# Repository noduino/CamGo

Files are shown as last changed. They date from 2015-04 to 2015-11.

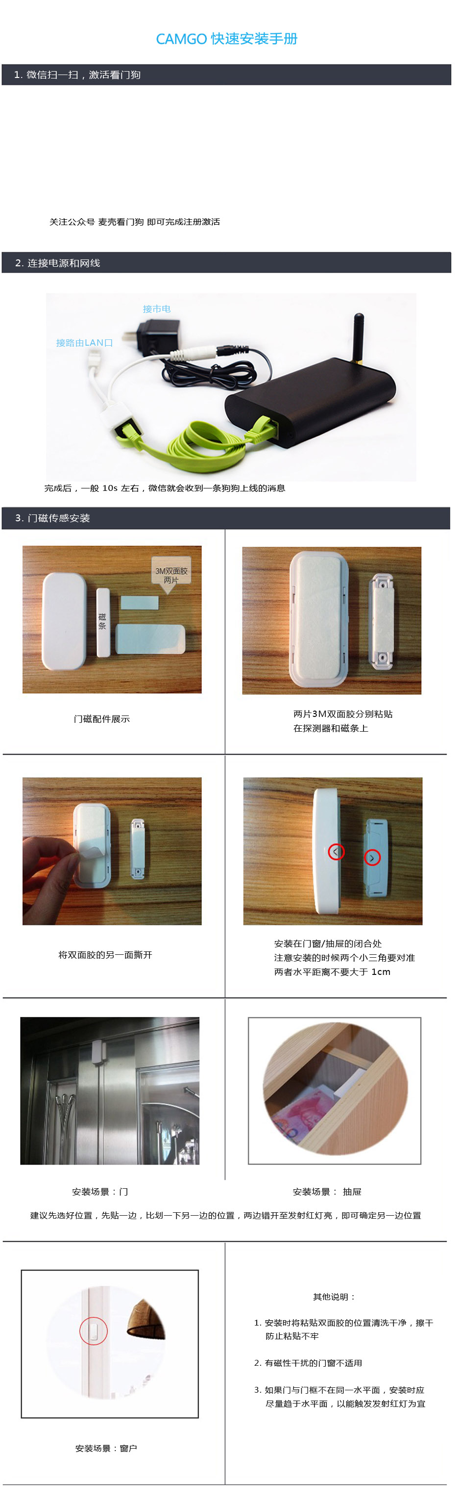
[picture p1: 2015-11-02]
user-manual.jpg

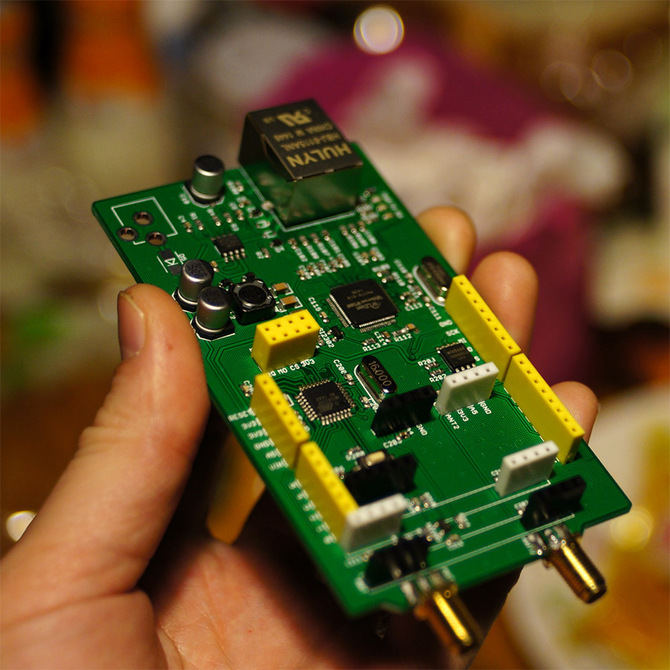
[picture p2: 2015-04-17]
Geek.Board.jpg

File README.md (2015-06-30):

# CamGo
Smart Home Dog to monitor 315&433MHz Sensors, Switches ...

Sensors:

  * door open sensor
  * wireless door bell
  * smoke detection (wireless alarm)
  * gas detection (wireless alarm)
  * wind & rain sensor
  ......

Switchs:

  * 315/433 light switch
  * dooya curtion
  * automatic window
  ......

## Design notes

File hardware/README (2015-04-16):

Copyright 2015 MaiKe Labs

These files are part of CamGo.

This is a free hardware design; you can redistribute it and/or modify
it under the terms of the GNU General Public License as published by
the Free Software Foundation; either version 2, or (at your option)
any later version.

This design is distributed in the hope that it will be useful,
but WITHOUT ANY WARRANTY; without even the implied warranty of
MERCHANTABILITY or FITNESS FOR A PARTICULAR PURPOSE.  See the
GNU General Public License for more details.

You should have received a copy of the GNU General Public License
along with this design; see the file COPYING.  If not, write to
the Free Software Foundation, Inc., 51 Franklin Street,
Boston, MA 02110-1301, USA.

CamGo is a Smart Home Gateway for 315MHz, 433MHz Sensors and Switches 

hardware notes:

Schematic and layout files were designed in Eagle.

PCB description: 2 layer PCB 0.062 in
    Copper        1   0.5 oz foil plated to approximately 0.0017 in
    Copper        2   0.5 oz foil plated to approximately 0.0017 in

FR4 or similar substrate with Er=4.5 (+/- 0.1)
double side solder mask green
single side silkscreen white
6 mil min trace width and
6 mil min isolation

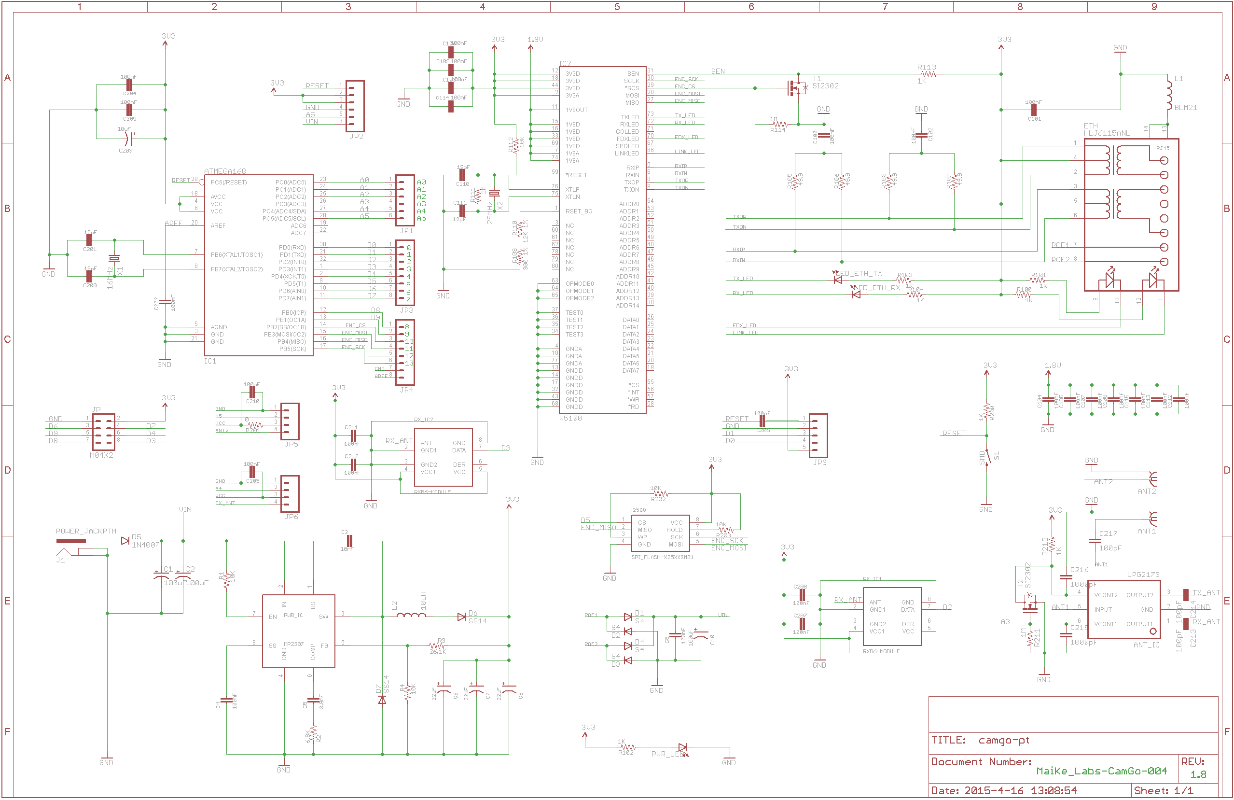
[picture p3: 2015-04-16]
hardware/CAMGO-SCH.png

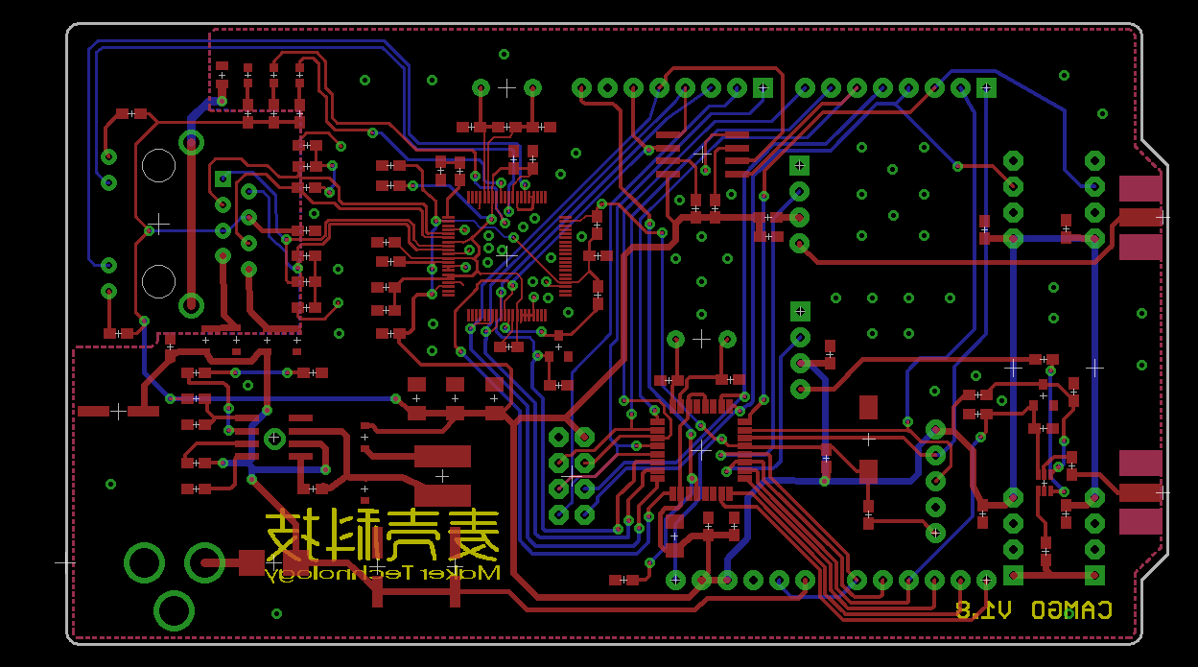
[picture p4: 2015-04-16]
hardware/CAMGO-BRD.png

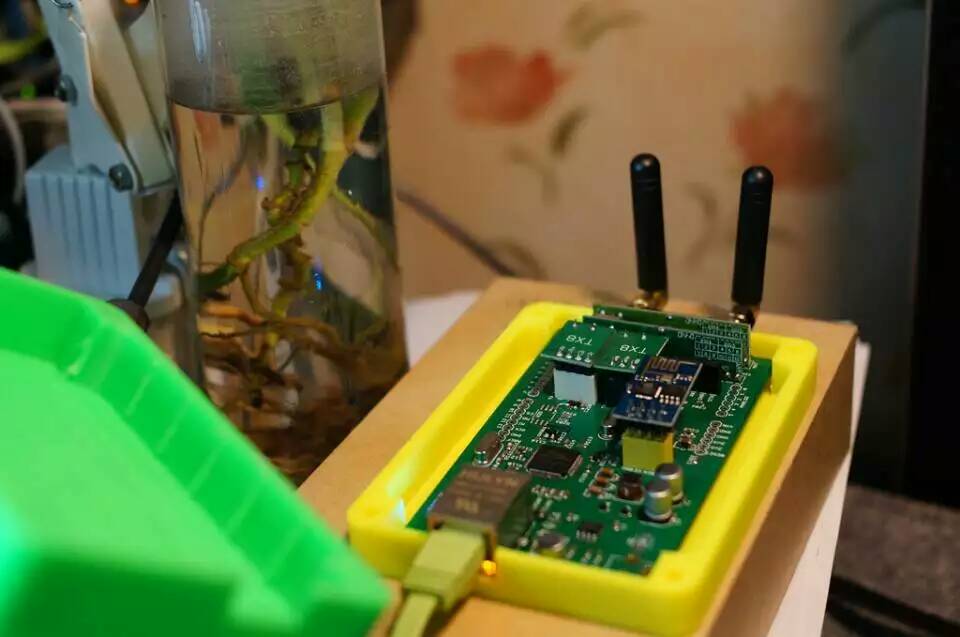
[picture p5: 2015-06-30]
shell/dogy/dogy-02.jpg

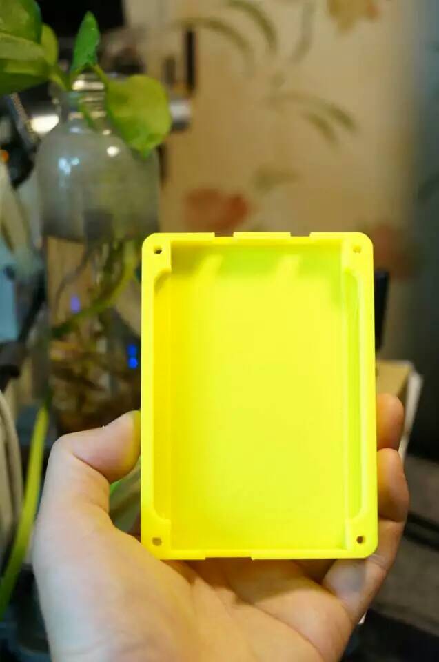
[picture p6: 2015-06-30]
shell/dogy/dogy-01.jpg

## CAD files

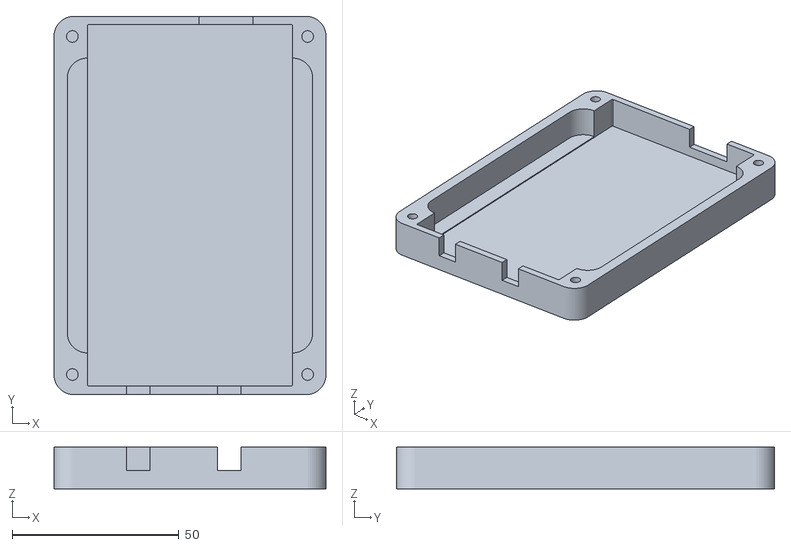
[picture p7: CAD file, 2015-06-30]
shell/dogy/dogy-bottom-v1.stl
81.5 x 113.2 x 12.5

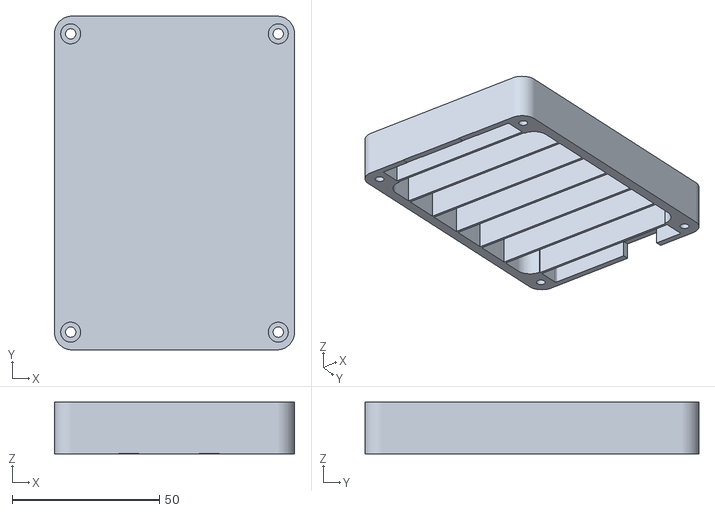
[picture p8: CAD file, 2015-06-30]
shell/dogy/dogy-lid-v1.stl
81.5 x 113.2 x 17.6

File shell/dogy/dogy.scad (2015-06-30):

include <../lib/plus.scad>

thick=1.6+0.25+0.5;
w=61.22+0.25; //compasate 0.3
len=108+0.25;

$fn=60;

boxh=26; //internal
boxbh=12.5;
tb_thick=2; // top,bottom wall thick

module ethernet(quad=3) {
    // we go 'underground' as we need to poke space into the case
    color("silver") 
      Quad(21.12, 15.92, quad) 
       Cube(size=[21.12+6, 15.92+0.25, 13.3]);
}

module sma(){
    
   Cube(7,45,7);
}

module board(h){ //h: cut the box
  
  onboard=thick+1.15; //include the bottom pin
  //base pcb
  color("darkgreen")
     CubeR(w, len, h, r=0.5); //+15 for dig hole
  
  //eth port
  translate([w/2-12-15.92,len/2,onboard])//bottom pin 1.5
     rotate(90)
      ethernet();
    
  //ant
  for(p=[(w/2-7-12),-15.5])
     translate([p,-len/2,onboard])//z, on the board
       sma();
    
}


module holes(){

    translate([0, pad,2]) //board, 2: bootom thick
       //
       difference(){
         board(boxh);
      
       }
       
    // translate([0,7+pad-5,boxbh-2*pad]) //board
      //   Cube(w, len+5, boxh-boxbh-thick);
     
     translate([0,0])
       scatter_conner([w+9,len-7])
          up(-pad)hextraper();//screw mount
     /*
     translate([0,-len/2+3])
        translate([0,-150/2])
           up(-pad)Cube(150,150,50);//screw mount
     */
     translate([w/2,0])
         up(thick)CubeR(12,len-20,25, r=6);//screw mount
     translate([-w/2,0])
         up(thick)CubeR(12,len-20,25, r=6);//screw mount
       
    
}
module box(){
  wallthick=10;  
 
  difference(){
        //base
        union(){
        
            CubeR(w+wallthick*2, len+wallthick/2, boxh+tb_thick*2, r=6);

       }
    
    //holes
      difference(){
       holes();
       for (p=[0,15,30,45,-15,-30,-45])
           translate([0,p])
            Cube(w+50,1,boxh);
      }
   }

}

//testant();



module lid(){
    
  intersection(){
      box();
      up(boxbh-0.1)
        Cube(500,500,25);
  }
   
}

module blid(){
    
  difference(){
      box();
      up(boxbh)
        Cube(200,200,25);
  }
    
     
    
}

//box();
//blid();
//rotate([0,180])up(-boxh-tb_thick*2)
lid();



module testeth(){
intersection(){
  box();

 translate([0,len/2,0])
   Cube(w+5,20,33);

}

}



module testant(){
intersection(){
  box();
 translate([0,-len/2,0])
   Cube(w+5,18,44);

}

}


module hextraper(len=15){
    
    
          translate([0,0, 0])
         	    cylinder($fn=6, r2=(6.26+0.2)/2,r1=(6.26+0.7)/2, h=5);
          translate([0,0, 5+0.5])
		     	cylinder($fn=33, r=3.5/2, h=50);
           
          // sink screw
          //translate([0,0, -11.3])cylinder($fn=33, r2=3.4/2,r1=6.8/2, h=3);
          // screw slot
          translate([0,0,15])cylinder($fn=33, d=6.8,h=35);

}

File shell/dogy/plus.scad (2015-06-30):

pad=0.05; /*make sure no malform or wrong object*/


green=[0.1,0.9,0.2,0.8];
black=[0.3,0.3,0.3,1];

fgreen=[0.3, 0.9, 0.2, 0.95];
fgold=[1,0.85, 0.1, 0.95];
fblue=[0.2,0.2,0.79];

//position helper
function cot(x)=1/tan(x);

module up(z){
    translate([0,0,z])
      children();
}

//basic shape 
module Cube(x,y,z,size){
  

   //echo("size", size);
   if(size){
     translate([0,0,size[2]/2])
       cube(size,center=true);
   }else{
     translate([0,0,z/2])
       cube([x,y,z],center=true);
     
   }


}

//test
//Cube(13,13,3);

module chamfer_cylinder(r,d,h,ch,crt,cdt,cdb,crb)
{
 	union(){
		 translate([0,0,h-ch])
	    	 cylinder(r1=r,d1=d, r2=crt,d2=cdt,h=ch);
         translate([0,0,ch])
  	       cylinder(r=r,d=d,h=h-ch*2);
         cylinder(r2=r,d2=d, r1=crb,d1=cdb,h=ch);
	}
}

module M3HexScrew(len=10, r=3){
      chamfer_cylinder(r=r/2,h=len-2*2, ch=2,crt=r/2,crb=7/2);
}


//chamfer_cylinder(r=10, h=10, crt=15,crb=15,ch=3);




/////////////////////////////////////////////////////////
// position helper
module quadI(x, y){
    translate([x/2, y/2]){
       children();    
    }
}
module quadII(x, y){
    translate([-x/2, y/2]){
       children(); 
    }
}
module quadIII(x, y){
    translate([-x/2, -y/2]){
       children();    
    }
    
}
module quadIV(x, y){
    translate([x/2, -y/2]){
       children();    
    }
}
module Quad(x, y, quad=0){

   if(quad==1)
       quadI(x,y)
            children();
   if(quad==2)
       quadII(x,y)
            children(); 
   if(quad==3)
       quadIII(x,y)
            children(); 
   if(quad==4)
       quadIV(x,y)
        children(); 

}
/////////////////////////////////////////////////////////
module scatter_conner(size=[0,0,0]){
    /*given x,y, (z) get 4 corner coordinates
                 Y
                /
          [2,  / 1]
         -----+---->X
         [3, /   4]
    */
    x=size[0]/2.0;
    y=size[1]/2.0;
    z=size[2];
    vet=[[ x,  y, z],
            [-x,  y, z],
            [-x, -y, z],
            [ x, -y, z]
        ];
    for (v=vet)
       translate(v)
          children();
}

/////////////////////////////////////////////////////////

module Sphere(r=none, d=none){
  if(r)
     translate([0,0,r])
     sphere(r=r);
  else
     translate([0,0,d/2]) 
     sphere(d=d);
}

//Sphere(d=3);




module CubeR(x,y,z,r){ CubeRZ(x=x,y=y,z=z,r=r);}
module CubeRZ(x,y,z,r){ CubeRXYZ(x=x,y=y,z=z,rz=r);}
module CubeRY(x,y,z,r){ CubeRXYZ(x,y,z,ry=r);}
module CubeRX(x,y,z,r){ CubeRXYZ(x,y,z,rx=r);}
module CubeRR(x,y,z,r){CubeRXYZ(x=x,y=y,z=z,rx=r,ry=r,rz=r,rc=r);}
module CubeRXYZ(x,y,z,r,rx,ry,rz,rc){
    difference(){
        Cube(x=x,y=y,z=z);
        //z
        if(rz)
        for(q=[1:4])
          Quad(x,y,q) up(-pad) 
           _RoundSmooth(l=z+pad*2,r=rz);
        //y
        if(ry){
            for(q=[1:2])
              Quad(x,y,q) up(-pad)
                rotate([90,0,0])up(-pad)_RoundSmooth(l=y+2*pad,r=ry);
            for(q=[3:4])
               Quad(x,y,q)translate([0,y,z])
                rotate([90,0,0])up(-pad)_RoundSmooth(l=y+2*pad,r=ry);
        }
        //x
        if(rx){
            for(q=[2,3])
                Quad(x,y,q) up(-pad)
                  rotate([0,90,0])up(-pad)_RoundSmooth(l=x+2*pad,r=rx);
            for(q=[1,4])
                Quad(x,y,q) translate([-x,0,z])
                  rotate([0,90,0])up(-pad)_RoundSmooth(l=x+2*pad,r=rx);
       }
       
       if(rc){
        for(q=[1,2,3,4])
          Quad(x,y,q)
            _RoundSmoothConner(rc);
          for(q=[1,2,3,4])
          Quad(x,y,q)
            up(z)
            _RoundSmoothConner(rc);
       }
  }
    
}

module _RoundSmoothConner(r){
    translate([0,0,-r])
    difference() {
        Cube(r*2, r*2, r*2);
        
        for(q=[1:4])
          Quad(2*r,2*r,q)
            sphere(r);
        for(q=[1:4])
          up(2*r)
           Quad(2*r,2*r,q)
             sphere(r+pad);
     }
 }
//$fn=45;
//_RoundSmoothConner(r=5);
 module _RoundSmooth(r, l){
   //translate([-r,-r,0])
   difference(){
    Cube(2*r, 2*r, l);
     for(q=[1:4])
       Quad(2*r-pad,2*r-pad,q) //pad: critical for export water tight
           up(-pad)cylinder(r=r,h=l+2*pad);
   }
}
//CubeR(5,5,5,r=1);

//speed test
//for(i=[1:50]) translate([i*10,0,0]) %_CubeFR_(10,5*i,5, r=2);
//for(i=[1:50])translate([i*10,0,0]) %CubeR(10,5*i,5,r=2);

module Hex(width,thick){
  
  angle = 360/6;		// 6 pans
  side = width*cot(angle);
  for (i=[0,60, 120])
    rotate(i)  
       Cube(side,width,thick);
    
}


///////////////////////////////////////////////
//dropped 
module CubeR__slow(x,y,z,r){
  size=[x-2*r, y-2*r, 0];  
  
  hull(){
    scatter_conner(size)
       cylinder(r=r, h=z);  
  }   
    
}

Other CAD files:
shell/official/rear-panel.dwg
shell/official/frant-panel.dwg

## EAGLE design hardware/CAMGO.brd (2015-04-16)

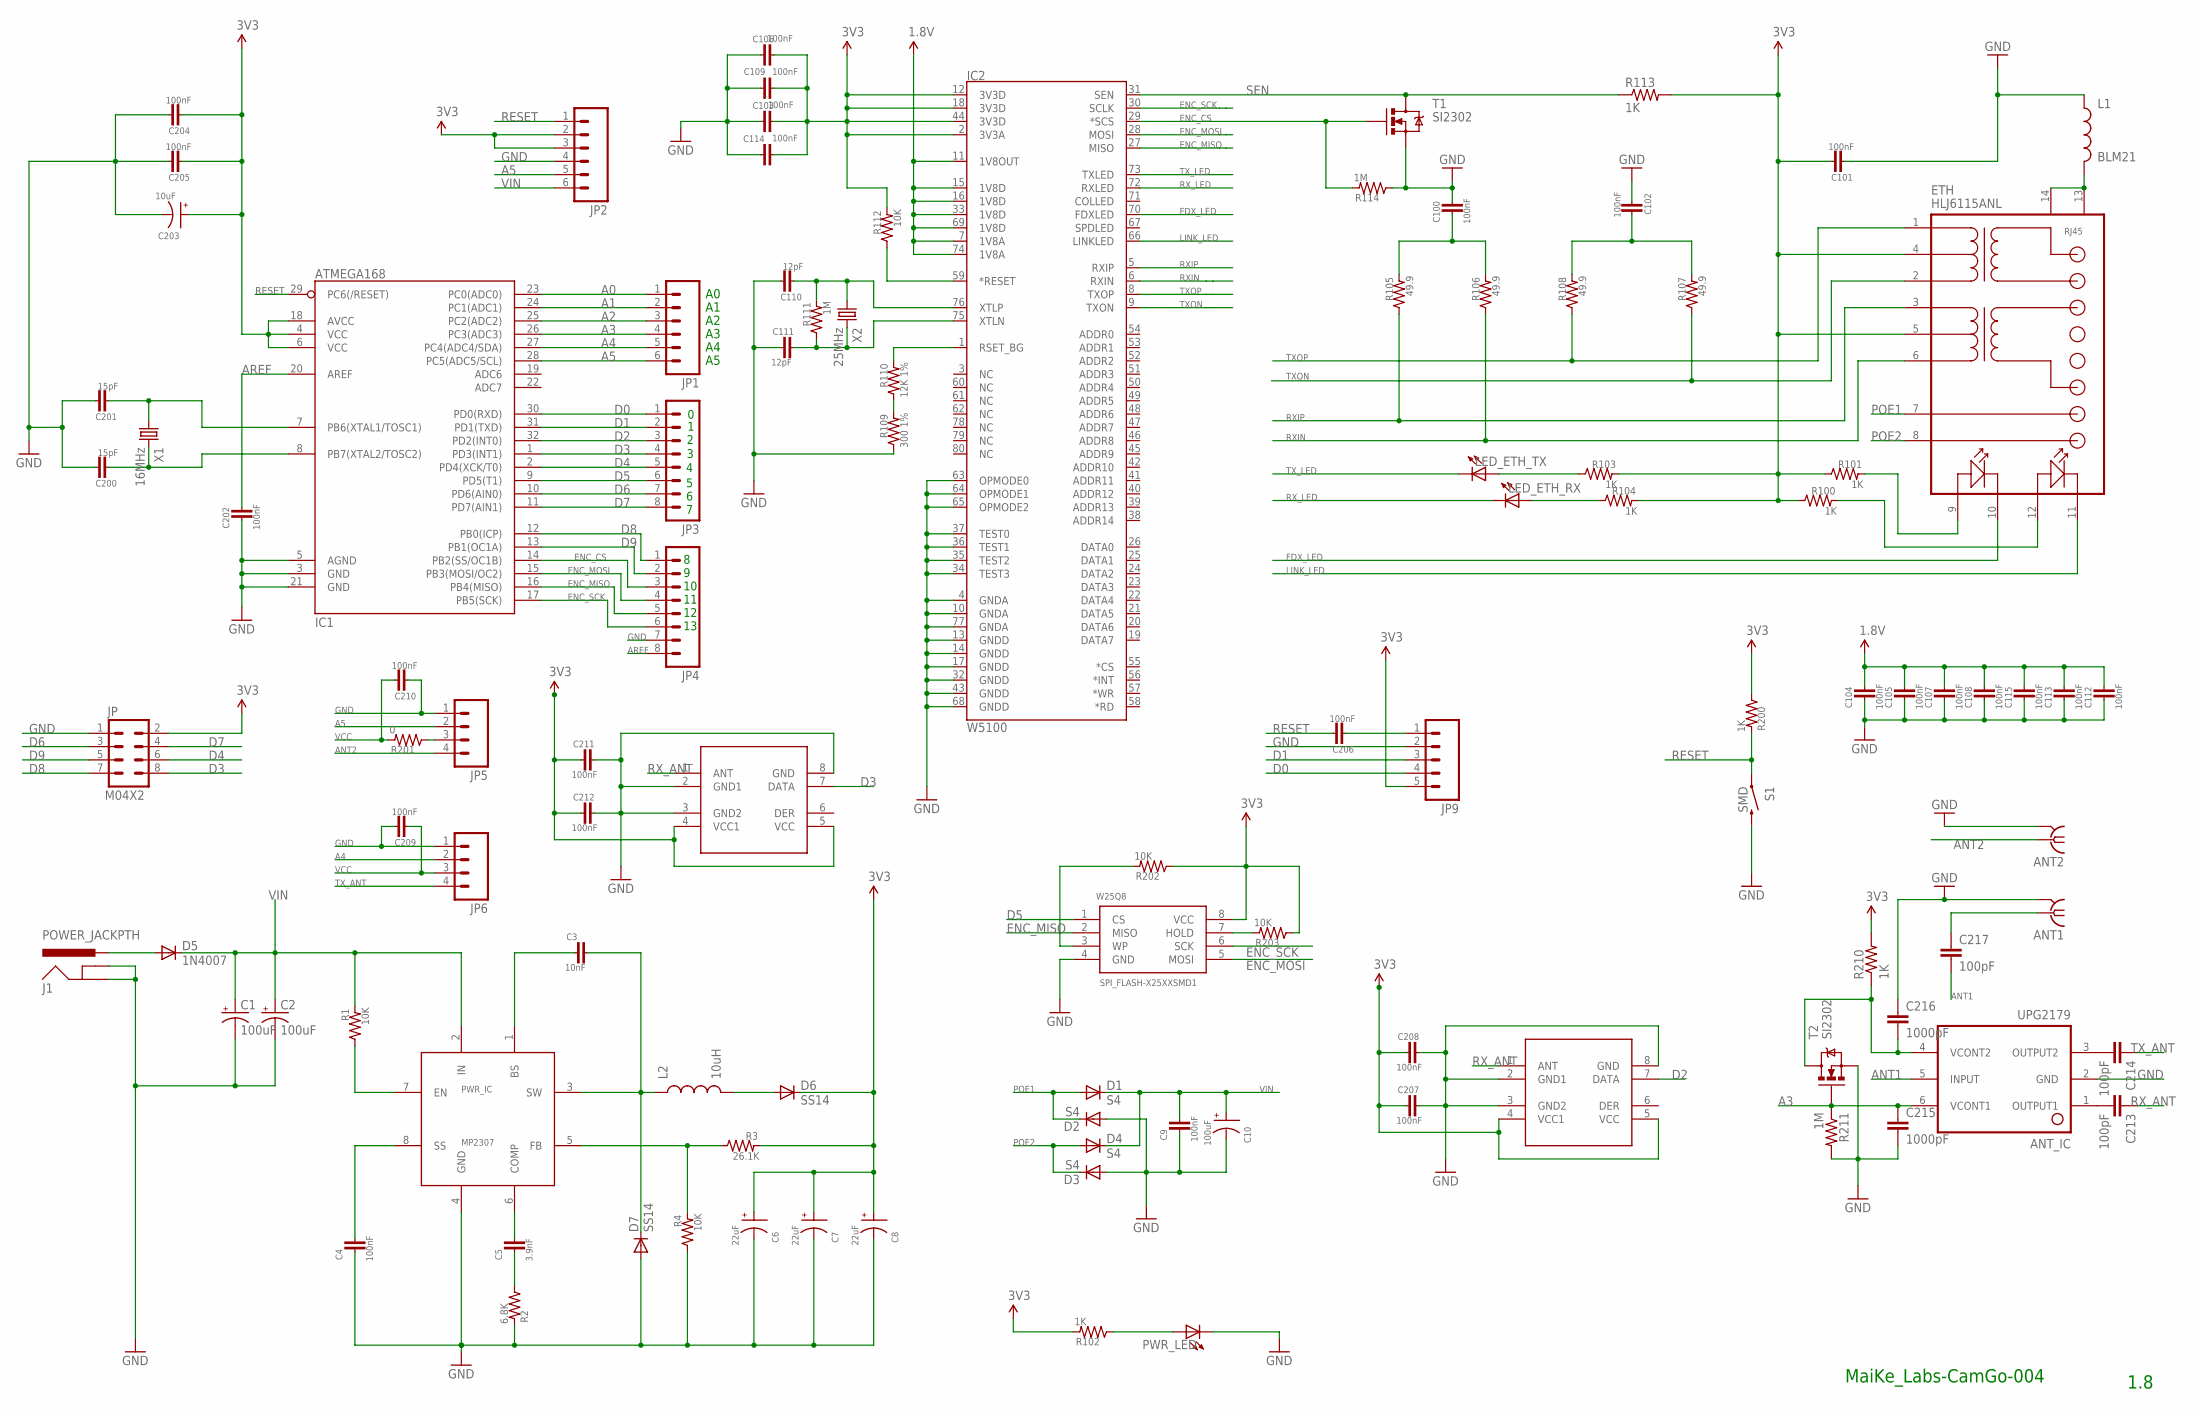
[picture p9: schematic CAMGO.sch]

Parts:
ANT1, ANT2: SMA--KE; SMA-KE
ANT_IC: UPG2179; SOT363
C1, C2, C10: 100uF; NIPPON_F80
C3: 10nF; 0603-CAP
C4, C9, C100, C101, C102, C103, C104, C105, C106, C107, C108, C109, C112, C113, C114, C115, C202, C204, C205, C206, C207, C208, C209, C210, C211, C212: 100nF; 0603-CAP
C5: 3.9nF; 0603-CAP
C6, C7, C8: 22uF; EIA3216
C110, C111: 12pF; 0603-CAP
C200, C201: 15pF; 0603-CAP
C203: 10uF; EIA3216
C213, C214, C217: 100pF; 0603-CAP
C215, C216: 1000pF; 0603-CAP
D1, D2, D3, D4: S4; SOD-323
D5: 1N4007; SMB-DIODE
D6, D7: SS14; SOD-323
ETH: HLJ6115ANL; HR911105A
IC1: ATMEGA168; TQFP32-08
IC2: W5100; LQFP-80
J1: POWER_JACKPTH; POWER_JACK_PTH
JP: M04X2; 2X4
JP1, JP2: M06SIP; 1X06
JP3, JP4: M081X08; 1X08
JP5, JP6: M04PTH; 1X04
JP9: M05PTH; 1X05
L1: BLM21; 0805
L2: 10uH; CR54
LED_ETH_RX: LED0603; LED-0603
LED_ETH_TX: LED0603; LED-0603
PWR_IC: MP2307; SOIC8
PWR_LED: LED0603; LED-0603
R1, R4, R112, R202, R203: 10K; 0603-RES
R2: 6.8K; 0603-RES
R3: 26.1K; 0603-RES
R100, R101, R102, R103, R104, R113, R200, R210: 1K; 0603-RES
R105, R106, R107, R108: 49.9; 0603-RES
R109: 300 1%; 0603-RES
R110: 12K 1%; 0603-RES
R111, R114, R211: 1M; 0603-RES
R201: 0; 0603-RES
RX_IC1, RX_IC2: RXB6-MODULE
S1: SMD; TACTILE-SWITCH-1101NE
T1, T2: SI2302; SOT23-3
W25Q8: SPI_FLASH-X25XXSMD1; SO08-EIAJ
X1: 16MHz; HC49US
X2: 25MHz; HC49US

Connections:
1.8V: C104.1, C105.1, C107.1, C108.1, C112.1, C113.1, C115.1, IC2.7 (1V8A), IC2.11 (1V8OUT), IC2.15 (1V8D), IC2.16 (1V8D), IC2.33 (1V8D), IC2.69 (1V8D), IC2.74 (1V8A)
A0: IC1.23 (PC0(ADC0)), JP1.1
A1: IC1.24 (PC1(ADC1)), JP1.2
A2: IC1.25 (PC2(ADC2)), JP1.3
A3: ANT_IC.6 (VCONT1), C215.1, IC1.26 (PC3(ADC3)), JP1.4, R211.1, T2.1 (G)
A4: IC1.27 (PC4(ADC4/SDA)), JP1.5, JP6.2
A5: IC1.28 (PC5(ADC5/SCL)), JP1.6, JP2.5, JP5.2
ANT1: ANT_IC.5 (INPUT), C217.2
ANT2: ANT2.1, JP5.4
AREF: C202.1, IC1.20 (AREF), JP4.8
D0: IC1.30 (PD0(RXD)), JP3.1, JP9.4
D1: IC1.31 (PD1(TXD)), JP3.2, JP9.3
D2: IC1.32 (PD2(INT0)), JP3.3, RX_IC1.7 (DATA)
D3: IC1.1 (PD3(INT1)), JP.8, JP3.4, RX_IC2.7 (DATA)
D4: IC1.2 (PD4(XCK/T0)), JP.6, JP3.5
D5: IC1.9 (PD5(T1)), JP3.6, W25Q8.1 (CS)
D6: IC1.10 (PD6(AIN0)), JP.3, JP3.7
D7: IC1.11 (PD7(AIN1)), JP.4, JP3.8
D8: IC1.12 (PB0(ICP)), JP.7, JP4.1
D9: IC1.13 (PB1(OC1A)), JP.5, JP4.2
ENC_CS: IC1.14 (PB2(SS/OC1B)), IC2.29 (*SCS), JP4.3, R114.2, T1.1 (G)
ENC_MISO: IC1.16 (PB4(MISO)), IC2.27 (MISO), JP4.5, W25Q8.2 (MISO)
ENC_MOSI: IC1.15 (PB3(MOSI/OC2)), IC2.28 (MOSI), JP4.4, W25Q8.5 (MOSI)
ENC_SCK: IC1.17 (PB5(SCK)), IC2.30 (SCLK), JP4.6, W25Q8.6 (SCK)
FDX_LED: ETH.10, IC2.70 (FDXLED)
GND: ANT1.G@1 (GND), ANT1.G@2 (GND), ANT1.G@3 (GND), ANT1.G@4 (GND), ANT2.G@1 (GND), ANT2.G@2 (GND), ANT2.G@3 (GND), ANT2.G@4 (GND), ANT_IC.2 (GND), C1.-, C2.-, C4.2, C6.C (-), C7.C (-), C8.C (-), C9.2, C10.-, C100.1, C101.2, C102.2, C103.2, C104.2, C105.2, C106.2, C107.2, C108.2, C109.1, C110.1, C111.2, C112.2, C113.2, C114.1, C115.2, C200.1, C201.1, C202.2, C203.C (-), C204.1, C205.1, C207.1, C208.1, C209.1, C210.2, C211.1, C212.1, C215.2, C216.1, D2.2 (A), D3.2 (A), D7.2 (A), IC1.3 (GND), IC1.5 (AGND), IC1.21 (GND), IC2.4 (GNDA), IC2.10 (GNDA), IC2.13 (GNDD), IC2.14 (GNDD), IC2.17 (GNDD), IC2.32 (GNDD), IC2.34 (TEST3), IC2.35 (TEST2), IC2.36 (TEST1), IC2.37 (TEST0), IC2.43 (GNDD), IC2.63 (OPMODE0), IC2.64 (OPMODE1), IC2.65 (OPMODE2), IC2.68 (GNDD), IC2.77 (GNDA), J1.GND, J1.GNDBREAK, JP.1, JP2.4, JP4.7, JP5.1, JP6.1, JP9.2, L1.1, PWR_IC.4 (GND), PWR_LED.C, R2.2, R4.1, R109.1, R114.1, R211.2, RX_IC1.2 (GND1), RX_IC1.3 (GND2), RX_IC1.8 (GND), RX_IC2.2 (GND1), RX_IC2.3 (GND2), RX_IC2.8 (GND), S1.P$2 (2), T1.2 (S), T2.2 (S), W25Q8.4 (GND)
LINK_LED: ETH.11, IC2.66 (LINKLED)
unnamed: ETH.9, R101.2
unnamed: C201.2, IC1.7 (PB6(XTAL1/TOSC1)), X1.1
unnamed: C200.2, IC1.8 (PB7(XTAL2/TOSC2)), X1.2
unnamed: C110.2, IC2.76 (XTLP), R111.2, X2.1
unnamed: R202.2, W25Q8.3 (WP)
unnamed: C206.2, JP9.1
unnamed: D5.A, J1.PWR
unnamed: C111.1, IC2.75 (XTLN), R111.1, X2.2
unnamed: C3.2, PWR_IC.1 (BS)
unnamed: PWR_IC.7 (EN), R1.1
unnamed: PWR_LED.A, R102.1
unnamed: C4.1, PWR_IC.8 (SS)
unnamed: IC2.1 (RSET_BG), R110.2
unnamed: R109.2, R110.1
unnamed: ETH.12, R100.2
unnamed: PWR_IC.5 (FB), R3.1, R4.2
unnamed: C102.1, R107.2, R108.2
unnamed: C5.1, PWR_IC.6 (COMP)
unnamed: C5.2, R2.1
unnamed: C3.1, D7.1 (C), L2.P$1 (1), PWR_IC.3 (SW)
unnamed: LED_ETH_TX.A, R103.1
unnamed: C100.2, R105.2, R106.2
unnamed: LED_ETH_RX.A, R104.1
unnamed: D6.2 (A), L2.P$2 (2)
unnamed: JP5.3, R201.1
unnamed: R203.2, W25Q8.7 (HOLD)
unnamed: ETH.13, ETH.14, L1.2
unnamed: ANT_IC.4 (VCONT2), C216.2, R210.1, T2.3 (D)
unnamed: ANT1.1, C217.1
unnamed: ANT_IC.1 (OUTPUT1), C213.2
unnamed: ANT_IC.3 (OUTPUT2), C214.2
POE1: D1.2 (A), D2.1 (C), ETH.7
POE2: D3.1 (C), D4.2 (A), ETH.8
RESET: C206.1, IC1.29 (PC6(/RESET)), IC2.59 (*RESET), JP2.1, R112.1, R200.2, S1.P$1 (1)
RXIN: ETH.6, IC2.6 (RXIN), R106.1
RXIP: ETH.3, IC2.5 (RXIP), R105.1
RX_ANT: C213.1, RX_IC1.1 (ANT), RX_IC2.1 (ANT)
RX_LED: IC2.72 (RXLED), LED_ETH_RX.C
SEN: IC2.31 (SEN), R113.1, T1.3 (D)
TXON: ETH.2, IC2.9 (TXON), R107.1
TXOP: ETH.1, IC2.8 (TXOP), R108.1
TX_ANT: C214.1, JP6.4
TX_LED: IC2.73 (TXLED), LED_ETH_TX.C
VCC: C6.A (+), C7.A (+), C8.A (+), C101.1, C103.1, C106.1, C109.2, C114.2, C203.A (+), C204.2, C205.2, C207.2, C208.2, C209.2, C210.1, C211.2, C212.2, D6.1 (C), ETH.4, ETH.5, IC1.4 (VCC), IC1.6 (VCC), IC1.18 (AVCC), IC2.2 (3V3A), IC2.12 (3V3D), IC2.18 (3V3D), IC2.44 (3V3D), JP.2, JP2.2, JP2.3, JP6.3, JP9.5, R3.2, R100.1, R101.1, R102.2, R103.2, R104.2, R112.2, R113.2, R200.1, R201.2, R202.1, R203.1, R210.2, RX_IC1.4 (VCC1), RX_IC1.5 (VCC), RX_IC2.4 (VCC1), RX_IC2.5 (VCC), W25Q8.8 (VCC)
VIN: C1.+, C2.+, C9.1, C10.+, D1.1 (C), D4.1 (C), D5.C, JP2.6, PWR_IC.2 (IN), R1.2

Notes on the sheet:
MaiKe_Labs-CamGo-004
1.8

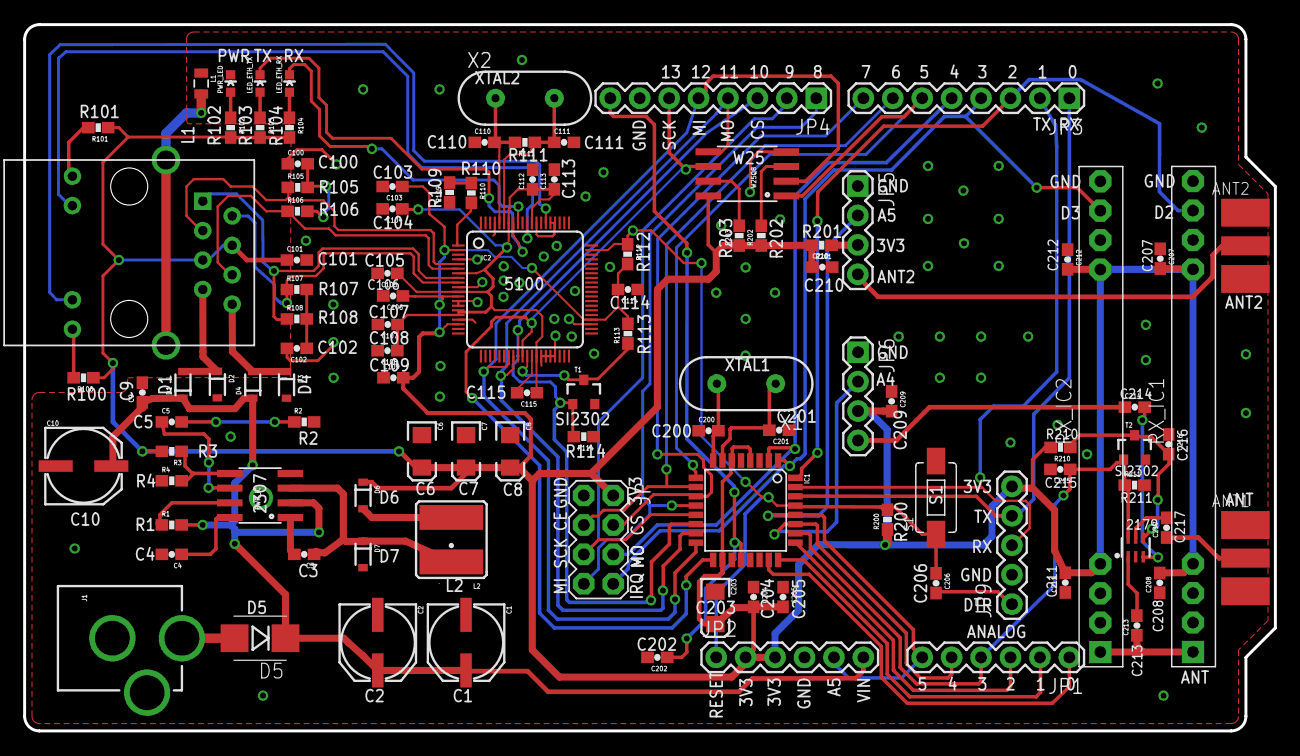
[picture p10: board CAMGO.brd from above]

Board: 2 copper layers, 108.0 x 61.0 mm, 105 parts (0 on the bottom side), 72 nets.

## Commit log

2015-04-16 hw: add the pcb sch file of camgo
    CAMGO.sch is the eagle format
    CAMGO-SCH.png is the png file exported from eagle
    [CAMGO.sch]
2015-04-16 hw: add the layout file of camgo
    CAMGO.brd is the eagle format file
    CAMGO-BRD.png is the png file exported from eagle
    [CAMGO.brd]
2015-04-17 add a board picture
2015-06-30 add a ABS/PLA shell
    It can be printed by 3D printer. It's designed by Yongli He (hyl)
    [dogy-bottom-v1.stl, dogy-lid-v1.stl, dogy.scad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]
2015-07-03 add the CAD files of official metal shell
    The front panel and rear panel need to order.
    The size of basic shell is 110x70x24mm. You can buy it from:
    http://item.taobao.com/item.htm?id=10605588774
    [frant-panel.dwg, rear-panel.dwg]
